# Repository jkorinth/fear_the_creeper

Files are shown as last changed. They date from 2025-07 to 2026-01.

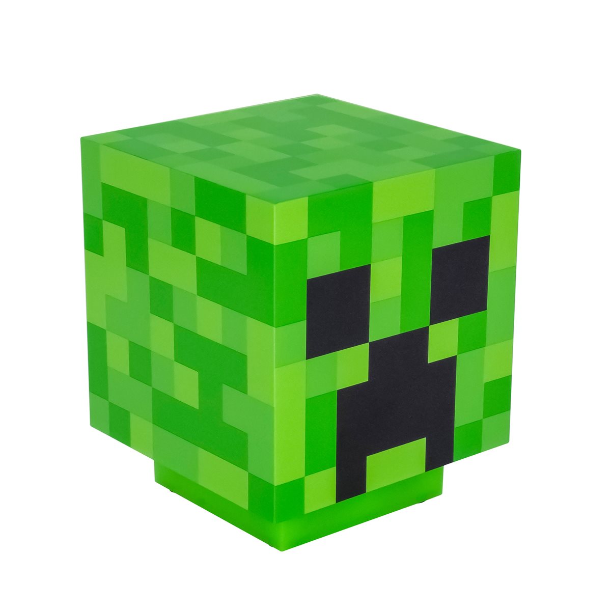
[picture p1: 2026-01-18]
creeper_head.jpg

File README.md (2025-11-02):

# Creeper Gadget

![Creeper][creeper.png]

A toy gadget that produces light + sound effects like a Creeper in Minecraft.
Fun little project which covers software, electronics, mechanical design elements.
And Mincraft. :)

## Hardware

* 35mm x 35mm 2-layer PCB w/dedicated ground plane
* Microcontroller: ATtiny85
* CR23xx battery
* Accelerometer: IIS328DQTR (low power, interrupt)
* piezzo buzzer
* 2x discrete LEDs (LP T67F)
* battery holder
* On/Off switch

## Mechanical

* 3D printed 40mm x 40mm x 10mm case
* cutout at Creeper "face" reveals black PCB underneath
* snap-fit lid for battery replacement
* hanger bracket for keyrings or lanyards

## Software

* IRQ-triggered sequence on motion detection
* fuse ignition sounds
* accelerating blinking
* explosion sound

## Tools

* Electronic Design: KiCAD
* Mechanical Design: FreeCAD
* Software Design: Arduino

## Current State ✅❌

### Summary
* i2c via I2CTinyBB: ✅
* irqs from IIS328DQ: ✅
* ISP: ✅
* LEDs: ✅
* KiBot CI/CD: kinda
* buzzer: ❌
* wake from sleep: ❌
* tilt switch: ❌

### Issues / Next Steps
Idea with the analog switch (74HC4066BQ) was nice, but it creates several new
problems: In closed state it has a small resistance (70R-180R), which creates
an accidental voltage divider with a pull-up on the line. Signal integrity was
good enough for i2c, strange enough, but both INT and BUZ suffered severe
issues when traversing the switch. The wake-up from deep sleep works fine when
bridging the `I2C` and `I2C_MCU` nets, but then ISP no longer works (which was
the whole point of having the analog switch in the first place).

The tilt switch has the issue that it generates only very short pulses, which
don't reliably wake up the MCU. Simplest solution would be a small capacitor
which slows down the rising edge, but I haven't tried that yet. Or a flip-flop
but that seems like total overkill.

This ISP issue is bugging me and I want to solve it. My next attempt would be
to use MOSFETs: 1x P-channel for the +3V pullups on SCL and SDA, 3x N-channel
for the SCL, SDA and INT signals. Costs more board space, but if I can use sth
like SOT-323, it may not be significant (also, the 74HC4066BQ footprint would
be gone, freeing up some little space).

Other issues:
  1. The power switch doesn't break the circuit from the debug connector.
  2. Add testpoints to make debugging less painful.

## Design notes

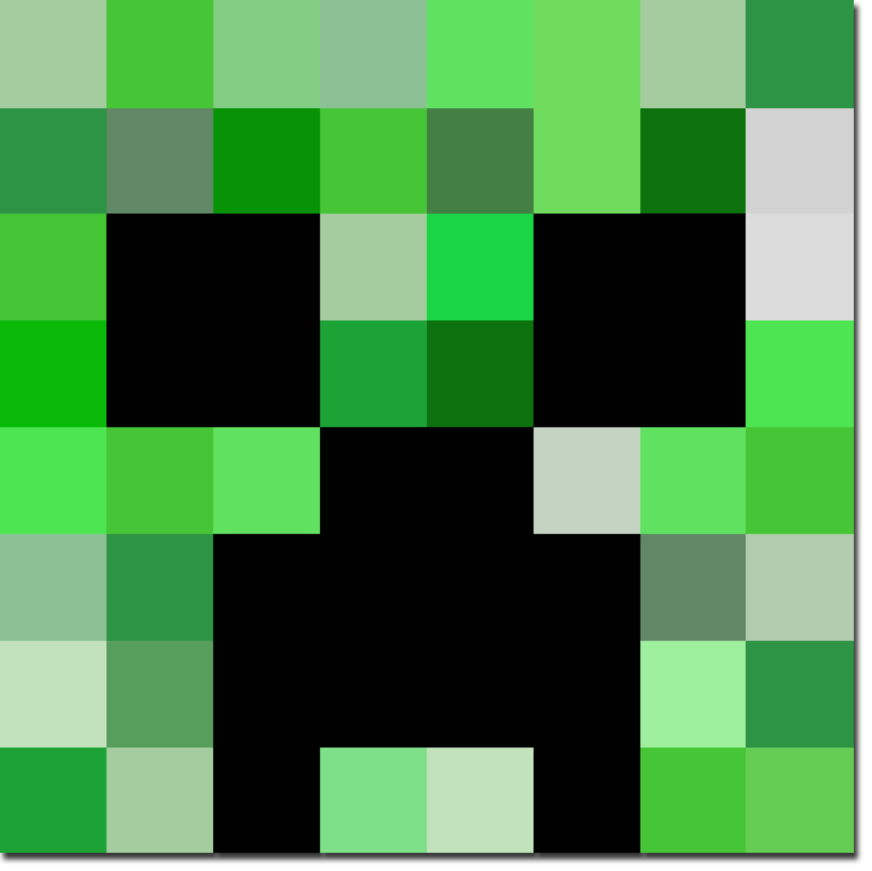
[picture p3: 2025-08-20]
case/creeper_face.webp

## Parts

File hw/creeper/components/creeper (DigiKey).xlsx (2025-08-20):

Reference | Qty | Value | Footprint | # | Manufacturer | MPN | SolderJoints | Original Part | Original Manufacturer | Matched Part Number | Matched Manufacturer | Part Match | Description | Qty | Selected Offers | Selected Distributor | Selected Distributor SKU | Selected Offers (Distributor Link) | Stock | Unit Price | Total Quantity | Total Price
BT1 | 1 | 3005 | creeper:BAT_3005 | 1 | Keystone Electronics | 3005 | 2 | 3005 | Keystone Electronics | 3005 | Keystone Electronics | Exact | Battery Holder: THM, 1 Coin Cell, 23mm, PhosBronze/Tin-Nickel | Keystone Electronics 3005 | 5 | DigiKey 36-3005-ND (https://octopart.com/opatz8j6/a1) | DigiKey | 36-3005-ND (https://octopart.com/opatz8j6/a1) | https://octopart.com/opatz8j6/a1 | 1407 | 0.43 | 5 | 2.15
C_ACC1, C_MCU1 | 2 | 100nF | Capacitor_SMD:C_0603_1608Metric_Pad1.08x0.95mm_HandSolder | 3 | KEMET | C0603C101K3RACTU | 2 | C0603C101K3RACTU | KEMET | C0603C101K3RACTU | KEMET | Exact | Ceramic Capacitor, Multilayer, Ceramic, 25V, 10% +Tol, 10% -Tol, X7R, 15% TC, 0.0001uF, Surface Mount, 0603 | 10 | DigiKey 399-14936-1-ND (https://octopart.com/opatz8j6/a1) | DigiKey | 399-14936-1-ND (https://octopart.com/opatz8j6/a1) | https://octopart.com/opatz8j6/a1 | 10727 | 0.109 | 10 | 1.09
C_PWR1 | 1 | 10uF | Capacitor_SMD:C_0805_2012Metric_Pad1.18x1.45mm_HandSolder | 4 | Murata Electronics | GRM21BZ71E106KE15L | 2 | GRM21BZ71E106KE15L | Murata Electronics | GRM21BZ71E106KE15L | Murata Electronics | Exact | 25V 10uF X7R ±10% 0805 Multilayer Ceramic Capacitors MLCC - SMD/SMT ROHS | 5 | DigiKey 490-GRM21BZ71E106KE15LCT-ND (https://octopart.com/opatz8j6/a1) | DigiKey | 490-GRM21BZ71E106KE15LCT-ND (https://octopart.com/opatz8j6/a1) | https://octopart.com/opatz8j6/a1 | 42211 | 0.25 | 5 | 1.25
D1, D2 | 2 | LED | creeper:LED_LG_T671-L2N1-1-Z | 5 | ams-OSRAM USA INC. | LG T67F-R1T1-24-1-20-R18-Z | 2 | LG T67F-R1T1-24-1-20-R18-Z | ams-OSRAM USA INC. | LG T67F-R1T1-24-1-20-R18-Z | ams-OSRAM USA INC. | Exact | SMT LED With Integrated Reflector | 10 | DigiKey 475-LGT67F-R1T1-24CT-ND (https://octopart.com/opatz8j6/a1) | DigiKey | 475-LGT67F-R1T1-24CT-ND (https://octopart.com/opatz8j6/a1) | https://octopart.com/opatz8j6/a1 | 24231 | 0.162 | 10 | 1.62
R1 | 1 | 0R | Resistor_SMD:R_0603_1608Metric_Pad0.98x0.95mm_HandSolder | 6 | Vishay Dale | CRCW06030000Z0EA | 2 | CRCW06030000Z0EA | Vishay Dale | CRCW06030000Z0EA | Vishay Dale | Exact | STANDARD THICK FILM CHIP RESISTOR Metal Glaze/thick Film, 0.1W, 0ohm, Surface Mount, 0603 | 5 | DigiKey 541-0.0GCT-ND (https://octopart.com/opatz8j6/a1) | DigiKey | 541-0.0GCT-ND (https://octopart.com/opatz8j6/a1) | https://octopart.com/opatz8j6/a1 | 1061434 | 0.014 | 10 | 0.14
U1 | 1 | ATtiny85V-10SU | Package_SO:SOIC-8_5.3x5.3mm_P1.27mm | 10 | Microchip Technology | ATTINY85V-10SU | 8 | ATTINY85V-10SU | Microchip Technology | ATTINY85V-10SU | Microchip Technology | Exact | AVR, 8K Flash, 512B Ee And SRAM, Usi, Adc, 8 Pins - 1.8V, 10MHZ, SOIC, Ind Temp, | 5 | DigiKey ATTINY85V-10SU-ND (https://octopart.com/opatz8j6/a1) | DigiKey | ATTINY85V-10SU-ND (https://octopart.com/opatz8j6/a1) | https://octopart.com/opatz8j6/a1 | 6425 | 1.27 | 5 | 6.35
U2 | 1 | LIS2DH12TR | creeper:LGA-12_STM | 11 | STMicroelectronics | LIS2DH12TR | 12 | LIS2DH12TR | STMicroelectronics | LIS2DH12TR | STMicroelectronics | Exact | Stmicroelectronics - LIS2DH12TR - 3-AXIS Accelerometer, Digital, LGA-12 | 5 | DigiKey 497-14851-1-ND (https://octopart.com/opatz8j6/a1) | DigiKey | 497-14851-1-ND (https://octopart.com/opatz8j6/a1) | https://octopart.com/opatz8j6/a1 | 30341 | 1.03 | 5 | 5.16

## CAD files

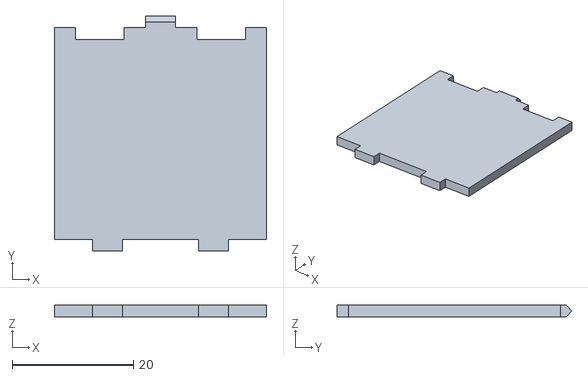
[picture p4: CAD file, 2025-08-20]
case/v3/creeper_case_v3_lidOD.stl
35.0 x 38.8 x 2.00

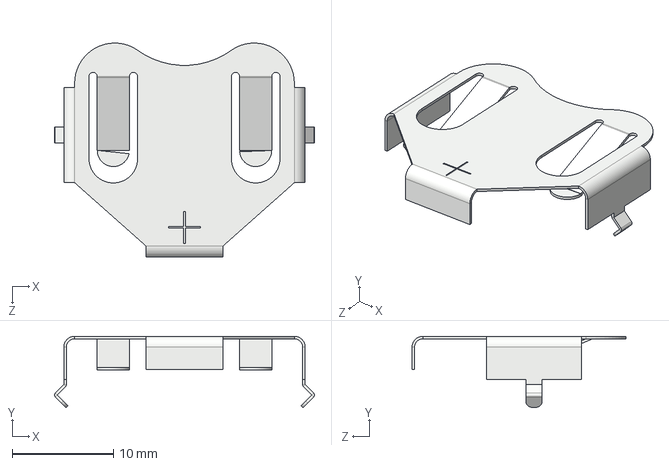
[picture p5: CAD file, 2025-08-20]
hw/creeper/components/3005/3005.step
25.7 x 7.06 x 21.1 mm

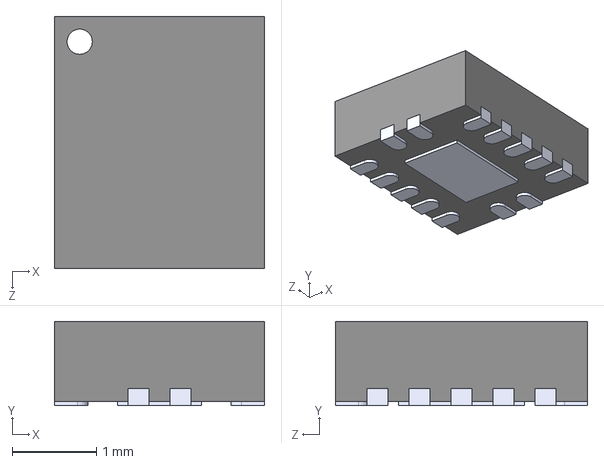
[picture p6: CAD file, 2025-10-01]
hw/creeper/components/74HC4066BQ-Q100/74HC4066BQ-Q100_11.step
2.50 x 1.00 x 3.00 mm

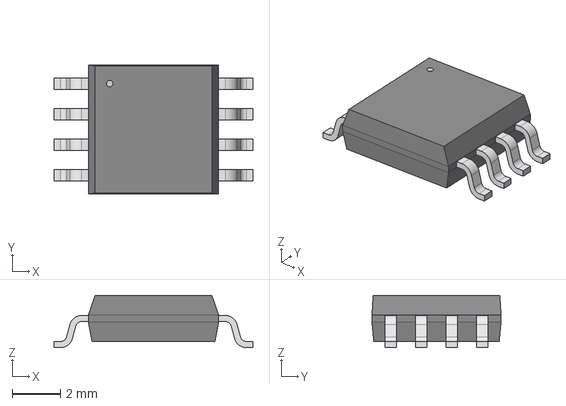
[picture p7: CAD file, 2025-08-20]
hw/creeper/components/ATTINY85V0-10SU/8S2_ATM.step
8.26 x 5.36 x 2.16 mm

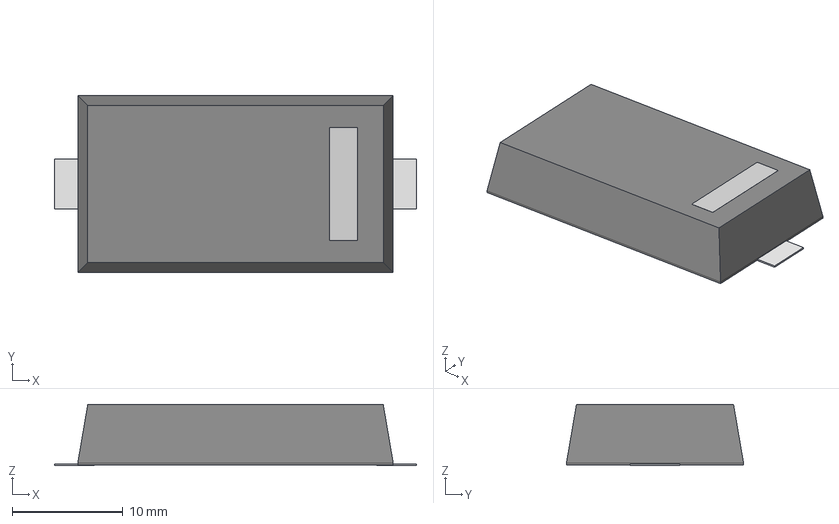
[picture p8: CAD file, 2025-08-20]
hw/creeper/components/BH-74G-5-P/BH-74G-5-P_ADM.step
32.7 x 16.0 x 5.52 mm

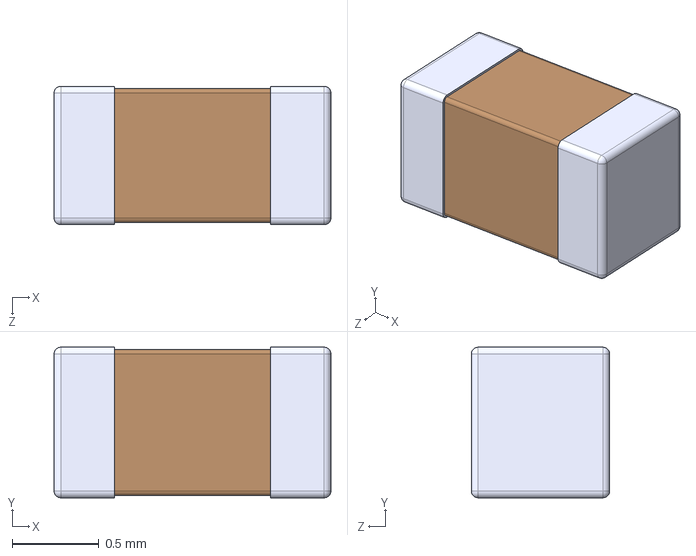
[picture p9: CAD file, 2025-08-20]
hw/creeper/components/C0603C101K3RACTU/C0603C101K3RACTU.STEP
1.60 x 0.87 x 0.8 mm

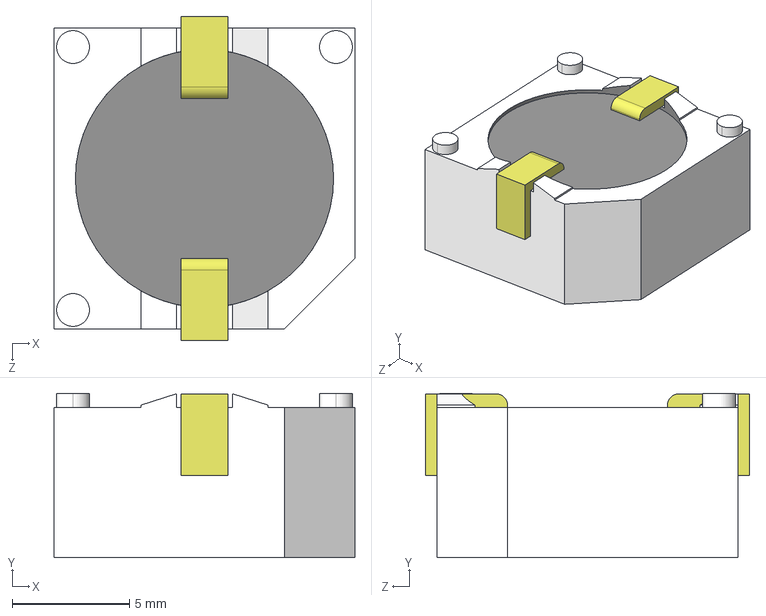
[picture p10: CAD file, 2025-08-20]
hw/creeper/components/CMT-1270S-SMT-TR/CMT-1270S-SMT.step
12.8 x 7.00 x 13.8 mm

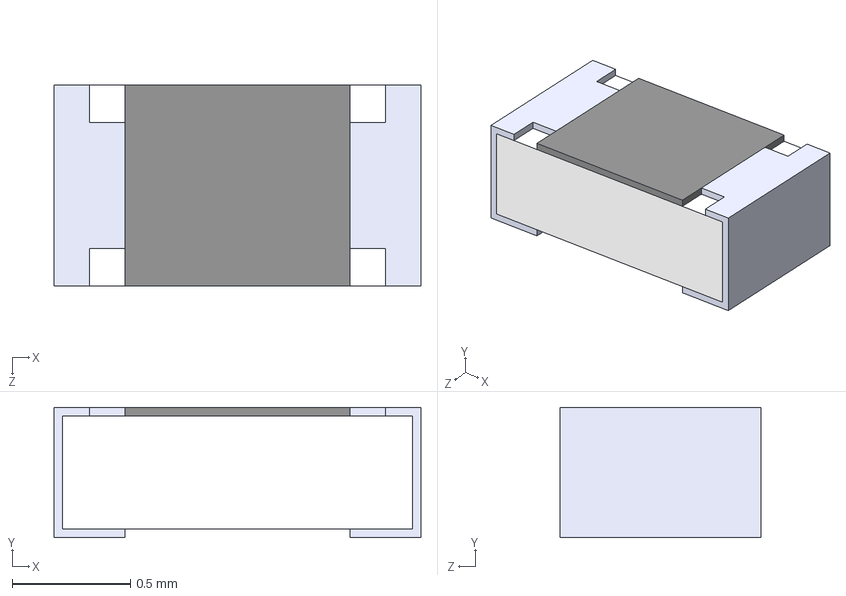
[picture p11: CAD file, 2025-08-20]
hw/creeper/components/CRCW060310K0JNEA/CRCW060310K0JNEA.STEP
1.55 x 0.55 x 0.85 mm

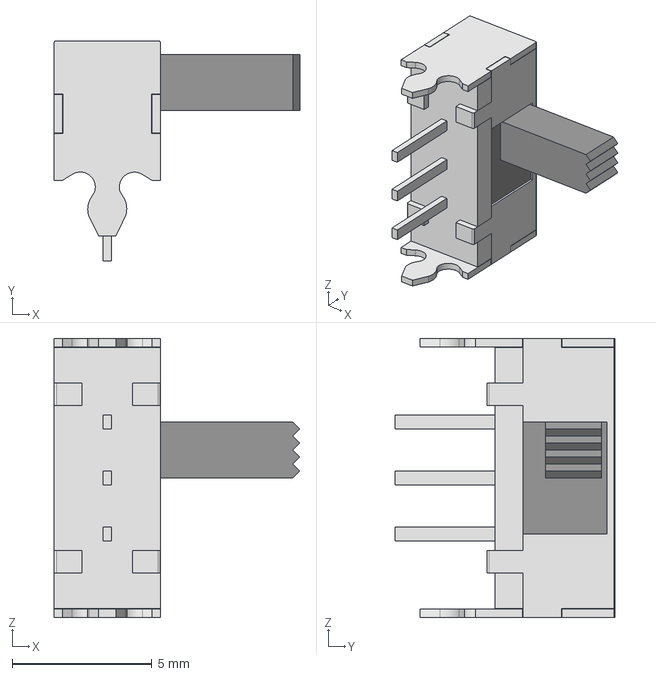
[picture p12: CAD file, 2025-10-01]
hw/creeper/components/EG1213/EG1213.step
8.80 x 7.90 x 10.00 mm

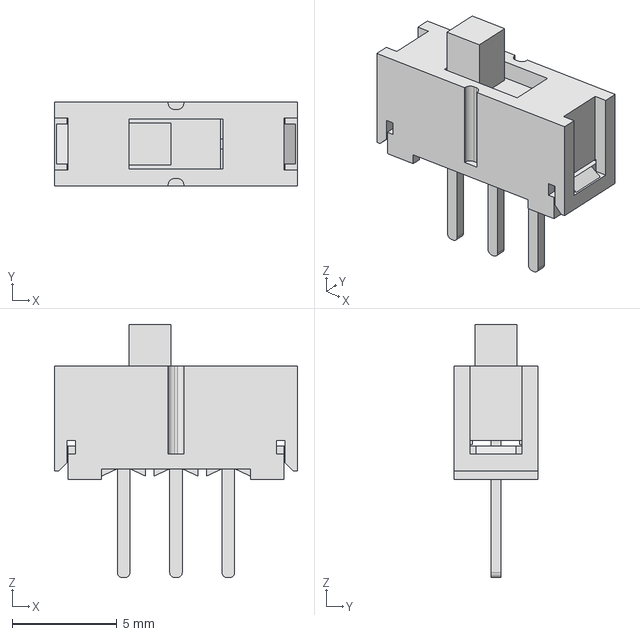
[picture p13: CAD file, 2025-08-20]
hw/creeper/components/EG1218/EG1218.step
11.6 x 4.00 x 12.1 mm

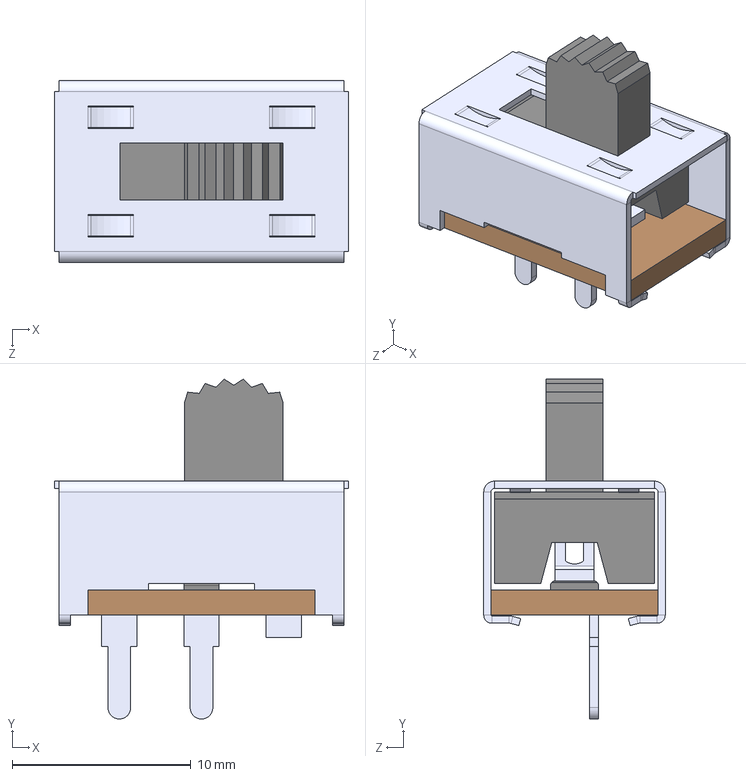
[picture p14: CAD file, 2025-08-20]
hw/creeper/components/GF-123-0054/GF-123-0054--3DModel-STEP-56544.STEP
16.5 x 19.0 x 10.2 mm

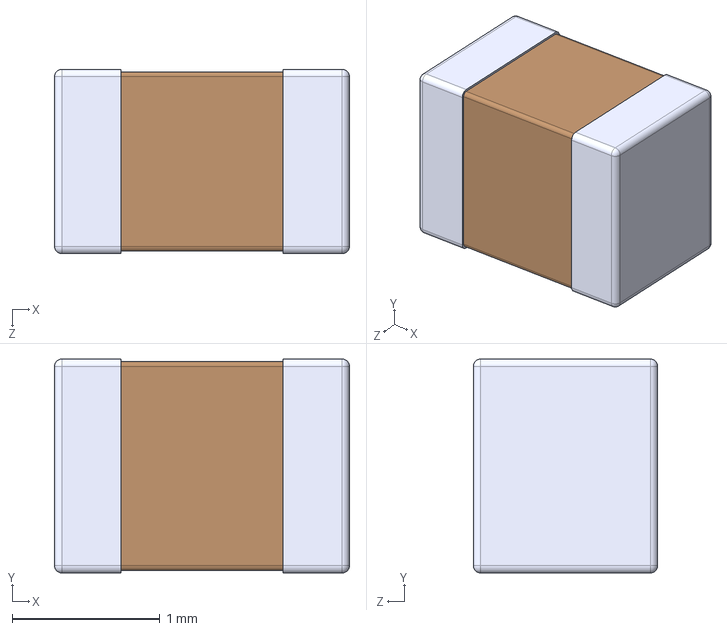
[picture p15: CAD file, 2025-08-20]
hw/creeper/components/GRM21BZ71E106KE15L/GRM21BZ71E106KE15L.STEP
2.00 x 1.45 x 1.25 mm

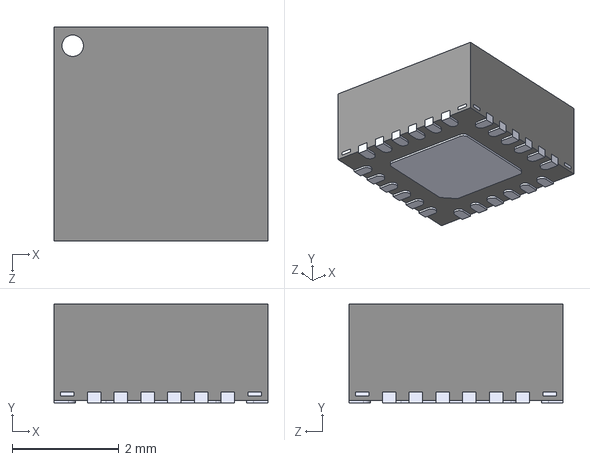
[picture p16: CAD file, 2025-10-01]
hw/creeper/components/IIS328DQTR.zip/IIS328DQTR.step
4.00 x 1.85 x 4.00 mm

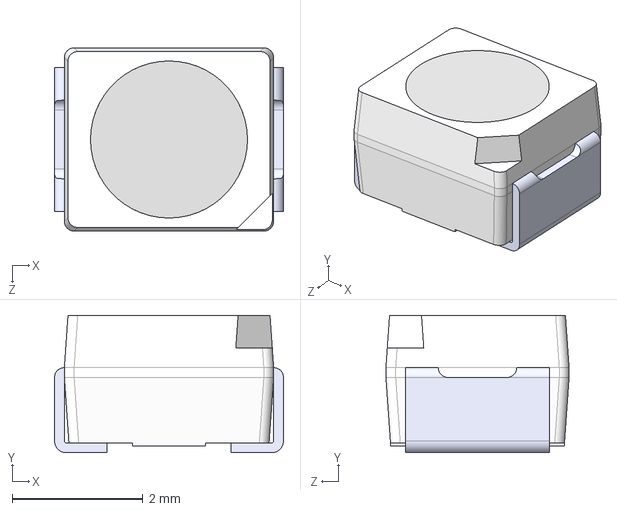
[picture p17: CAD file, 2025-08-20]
hw/creeper/components/LG_T67F-R1T1-24/LG T67F-R1T1-24.step
3.50 x 2.10 x 2.80 mm

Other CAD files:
hw/creeper/components/LIS2DH12TR/LGA-12_STM.step
hw/creeper/components/LP_T67F/LED_LPT67F-P1R2-35-1-20-R18_AMS.step
hw/creeper/components/PT_1241PFQ/PT-1241PFQ_MAL.step
case/v2/creeper_case_v2_case.stl
case/v2/creeper_case_v2_face.stl
case/v3/creeper_case_v3_case.stl
case/v3/creeper_case_v3_face.stl
hw/creeper/components/BH-74G-5-P/BH-74G-5-P_ADM.stl
hw/creeper/components/LP_T67F/LED_LPT67F-P1R2-35-1-20-R18_AMS.stl
hw/creeper/components/SMT-0825-S-2-R/SMT-0825-S-2-R.step
hw/creeper/components/SMT_1324_TW_1V_HT_R/SMT-1324-TW-1V-HT-R.step

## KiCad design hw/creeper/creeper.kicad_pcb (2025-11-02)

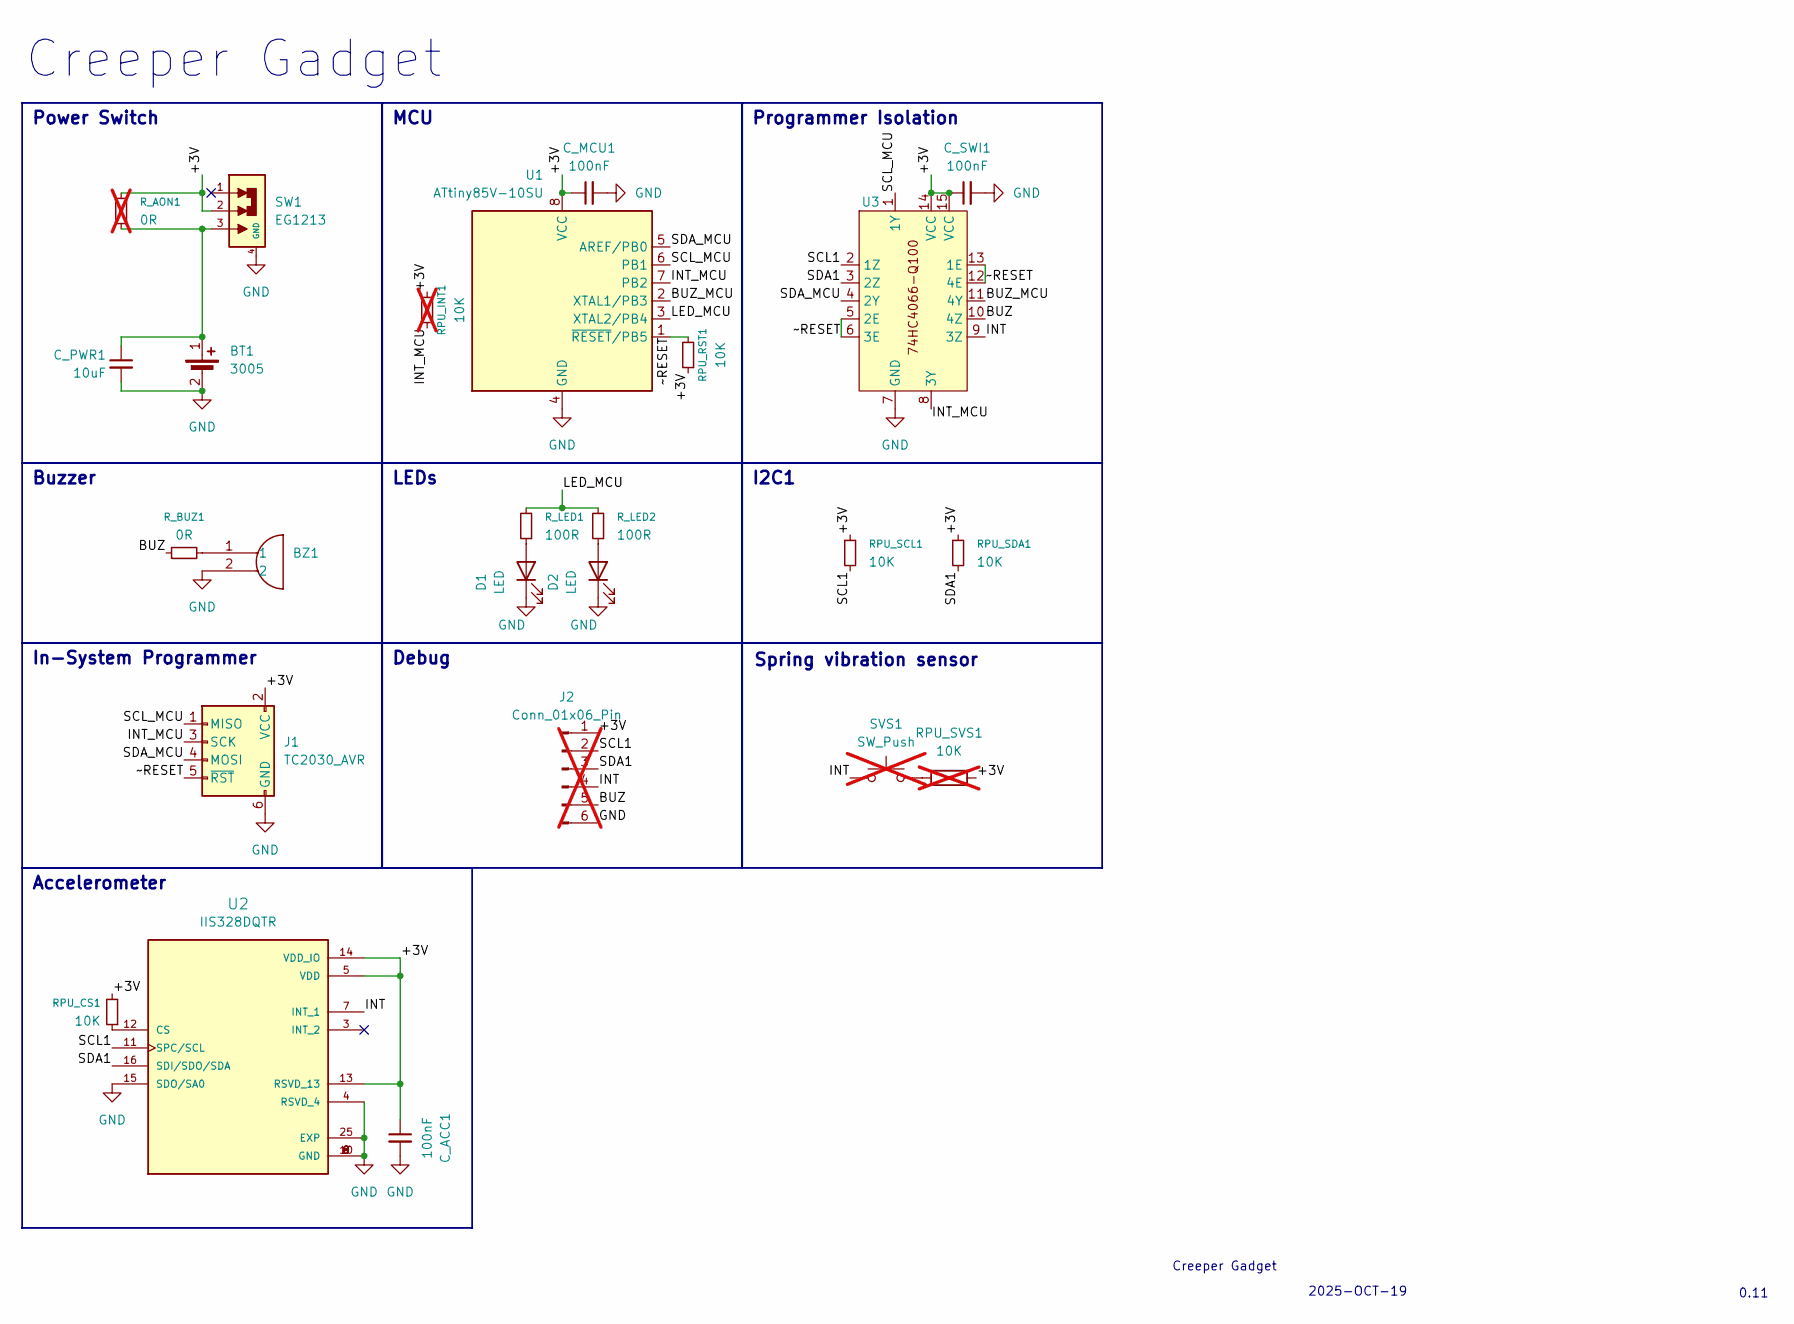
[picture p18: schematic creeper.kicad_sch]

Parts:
BT1: 3005; BAT_3005; MPN 3005
BZ1: XDCR_SMT-0825-S-2-R
C_ACC1: 100nF; C_0603_1608Metric_Pad1.08x0.95mm_HandSolder; MPN C0603C101K3RACTU
C_MCU1: 100nF; C_0603_1608Metric_Pad1.08x0.95mm_HandSolder; MPN C0603C101K3RACTU
C_PWR1: 10uF; C_0805_2012Metric_Pad1.18x1.45mm_HandSolder; MPN GRM21BZ71E106KE15L
C_SWI1: 100nF; C_0603_1608Metric_Pad1.08x0.95mm_HandSolder; MPN C0603C101K3RACTU
D1, D2: LED; LED_LG_T671-L2N1-1-Z; MPN LG T67F-R1T1-24-1-20-R18-Z
J1: TC2030_AVR; CON_TC2030_outlined
J2: Conn_01x06_Pin; PinHeader_1x06_P2.54mm_Vertical; not fitted
RPU_CS1: 10K; R_0603_1608Metric_Pad0.98x0.95mm_HandSolder; MPN CRCW060310K0JNEA
RPU_INT1: 10K; R_0603_1608Metric_Pad0.98x0.95mm_HandSolder; MPN CRCW060310K0JNEA; not fitted
RPU_RST1: 10K; R_0603_1608Metric_Pad0.98x0.95mm_HandSolder; MPN CRCW060310K0JNEA
RPU_SCL1: 10K; R_0603_1608Metric_Pad0.98x0.95mm_HandSolder; MPN CRCW060310K0JNEA
RPU_SDA1: 10K; R_0603_1608Metric_Pad0.98x0.95mm_HandSolder; MPN CRCW060310K0JNEA
RPU_SVS1: 10K; R_0603_1608Metric_Pad0.98x0.95mm_HandSolder; not fitted
R_AON1: 0R; R_0603_1608Metric_Pad0.98x0.95mm_HandSolder; not fitted
R_BUZ1: 0R; R_0603_1608Metric_Pad0.98x0.95mm_HandSolder; MPN CRCW06030000Z0EA
R_LED1, R_LED2: 100R; R_0603_1608Metric_Pad0.98x0.95mm_HandSolder; MPN CRCW060343R0JNEA
SVS1: SW_Push; SW_180xxP_Spring_Vibration_Sensor; not fitted
SW1: EG1213; SW_EG1213; MPN EG1213
U1: ATtiny85V-10SU; SOIC-8_5.3x5.3mm_P1.27mm; MPN ATTINY85V-10SU
U2: IIS328DQTR; IIS328DQTR_QFN50P400X400X185-25N; PARTREV 3; DigiKey_Part_Number 497-15701-1-ND
U3: QFN50P300X250X100-15N; MPN 74HC4066BQ-Q100,11

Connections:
/+3V: C_ACC1.1, C_MCU1.1, C_SWI1.1, J1.2 (VCC), J2.1, RPU_CS1.2, RPU_INT1.2, RPU_RST1.1, RPU_SCL1.1, RPU_SDA1.1, RPU_SVS1.2, R_AON1.1, SW1.2, U1.8 (VCC), U2.5 (VDD), U2.13 (RSVD_13), U2.14 (VDD_IO), U3.14 (VCC), U3.15 (VCC)
/BUZ: J2.5, R_BUZ1.1, U3.10 (4Z)
/BUZ_MCU: U1.2 (XTAL1/PB3), U3.11 (4Y)
/INT: J2.4, SVS1.1, U2.7 (INT_1), U3.9 (3Z)
/INT_MCU: J1.3 (SCK), RPU_INT1.1, U1.7 (PB2), U3.8 (3Y)
/LED_MCU: R_LED1.2, R_LED2.2, U1.3 (XTAL2/PB4)
/SCL1: J2.2, RPU_SCL1.2, U2.11 (SPC/SCL), U3.2 (1Z)
/SCL_MCU: J1.1 (MISO), U1.6 (PB1), U3.1 (1Y)
/SDA1: J2.3, RPU_SDA1.2, U2.16 (SDI/SDO/SDA), U3.3 (2Z)
/SDA_MCU: J1.4 (MOSI), U1.5 (AREF/PB0), U3.4 (2Y)
/~RESET: J1.5 (~RST), RPU_RST1.2, U1.1 (~RESET/PB5), U3.5 (2E), U3.6 (3E), U3.12 (4E), U3.13 (1E)
GND: BT1.2 (-), BZ1.2, C_ACC1.2, C_MCU1.2, C_PWR1.2, C_SWI1.2, D1.1 (K), D2.1 (K), J1.6 (GND), J2.6, SW1.4 (GND), U1.4 (GND), U2.4 (RSVD_4), U2.6 (GND), U2.8 (GND), U2.9 (GND), U2.10 (GND), U2.15 (SDO/SA0), U2.25 (EXP), U3.7 (GND)
unnamed: BT1.1 (+), C_PWR1.1, R_AON1.2, SW1.3
unnamed: BZ1.1, R_BUZ1.2
unnamed: D1.2 (A), R_LED1.1
unnamed: D2.2 (A), R_LED2.1
unnamed: RPU_SVS1.1, SVS1.2
unnamed: RPU_CS1.1, U2.12 (CS)

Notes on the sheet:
LEDs
Creeper Gadget
MCU
Creeper Gadget
I2C1
2025-OCT-19
Buzzer
Debug
Power Switch
Programmer Isolation
In-System Programmer
0.11
Spring vibration sensor
Accelerometer

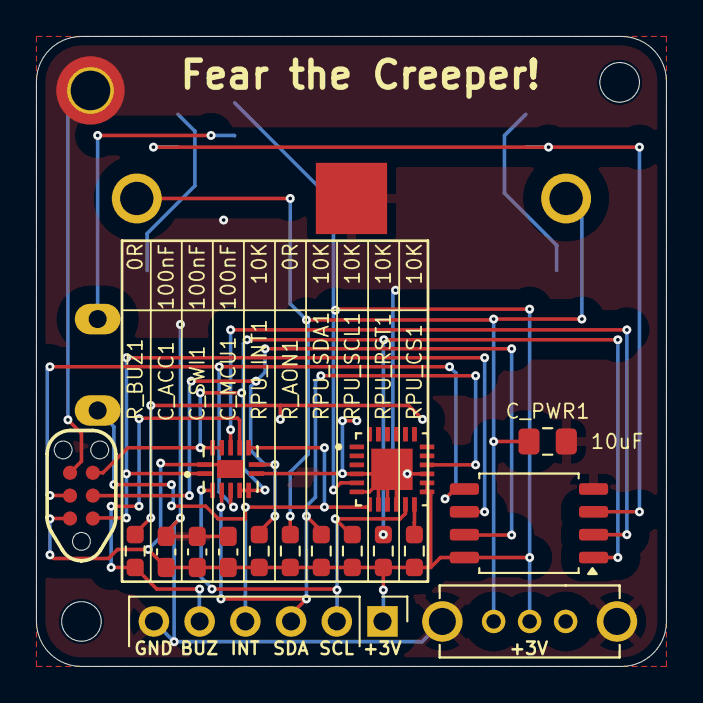
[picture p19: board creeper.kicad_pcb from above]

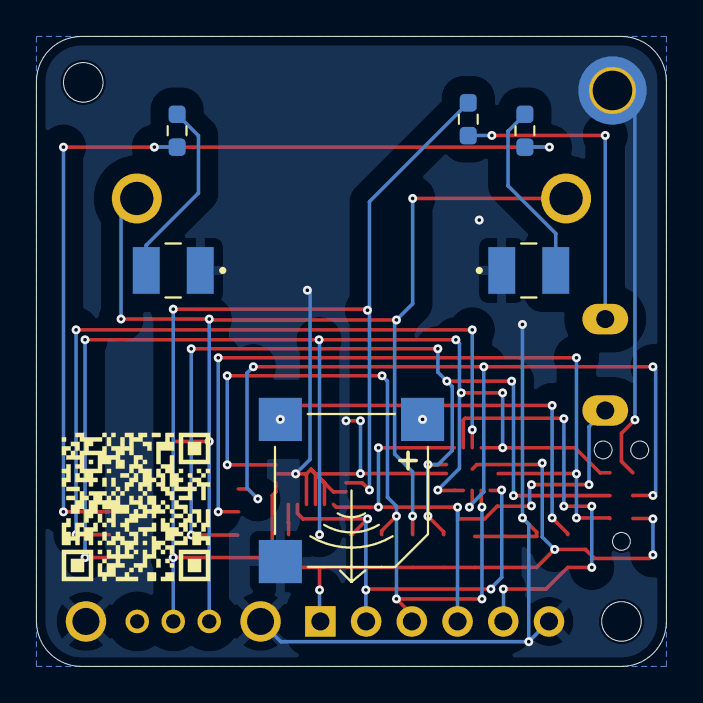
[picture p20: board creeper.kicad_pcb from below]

Board: 2 copper layers, 35.0 x 35.0 mm, 26 parts (8 on the bottom side), 18 nets.

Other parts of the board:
QR1: https://github.com/jkorinth/fear_the_creeper; github_jkorinth-fear_the_creeper

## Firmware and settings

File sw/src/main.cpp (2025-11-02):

#include <Arduino.h>
#include <I2CTinyBB.h>
#include <avr/interrupt.h>
#include <avr/power.h>
#include <avr/sleep.h>
#include "iis328dq.h"

#define INT 2
#define BUZ 3
#define LED 4

#define IIS328DQ_ADDR 0x18
#define REG_WHO_AM_I 0x0f
#define REG_CTRL_REG1 0x20

#define ARR_SZ(x) (sizeof((x)) / sizeof(*(x)))

volatile int _play = 1;

void iis328dq_init()
{
	uint8_t d = 0;
	for (size_t i = 0; i < IIS328DQ_INIT_COUNT; ++i) {
		uint8_t tmp[2] = { iis328dq_shake_init[i].reg, iis328dq_shake_init[i].value };
		I2CWrite(IIS328DQ_ADDR, tmp, 2);
		I2CReadReg(IIS328DQ_ADDR, tmp[0], &d, 1);
	}
}

void setup() {
  uint8_t d;
  clock_prescale_set(clock_div_1);
  DDRB = (1 << PB4) | (1 << PB3) | (1 << PB1) | (1 << PB0);
  PORTB = 0;
  MCUCR = 0; // low level-triggered interrupt
  GIMSK |= (1 << INT0);  // Enable INT0 external interrupt
  I2CInit(0, 1, 10);
  sei();
  iis328dq_init();
}

// Interrupt Service Routine for INT0
ISR(INT0_vect) {}

void enterSleep() {
  uint8_t d = 0;
  MCUCR = 0;
  GIMSK |= (1 << INT0);  // Enable INT0 external interrupt
  
  set_sleep_mode(SLEEP_MODE_PWR_DOWN);  // Set deep sleep mode
  sleep_enable();  // Enable sleep bit
  sei();  // Enable global interrupts
  sleep_cpu();  // Go to sleep - execution stops here
  
  // Code resumes here after wake-up
  sleep_disable();  // Disable sleep bit
  GIMSK &= ~(1 << INT0);  // disable INT0 external interrupt
  I2CReadReg(IIS328DQ_ADDR, IIS328DQ_INT1_SRC, &d, 1);
  _play = 1;
}

void play()
{
	int countdown = 700;
	while (countdown > 0) {
		digitalWrite(LED, HIGH);
		delay(25);
		digitalWrite(LED, LOW);
		countdown *= 0.84;
		delay(countdown);
	}
	_play = 0;
}

void loop() {
	if (_play) {
		play();
	}
	enterSleep();
}

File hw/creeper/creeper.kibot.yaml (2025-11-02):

kibot:
  version: 1

import:
- file: ExportProject
- file: JLCPCB
  definitions:
    _KIBOT_MANF_DIR: Manufacturers/JLCPCB
    _KIBOT_POS_PRE_TRANSFORM: '[''_kicost_rename'', ''_rot_footprint'']'
    _KIBOT_BOM_ENABLED: 'false'
- file: PCB2Blender_2_1
- file: PCBWay
  definitions:
    _KIBOT_MANF_DIR: Manufacturers/PCBWay

preflight:
  drc:
    dont_stop: true
    format: HTML,RPT
  erc:
    dont_stop: true
    format: HTML,RPT

outputs:
- name: basic_export_3d_step
  comment: 3D model in STEP format
  type: export_3d
  dir: 3D
  options:
    format: step
- name: basic_export_3d_stl
  comment: 3D model in STL format
  type: export_3d
  dir: 3D
  options:
    format: stl
- name: gerber_modern
  comment: Gerbers in modern format, recommended by the standard
  type: gerber
  dir: Gerbers
  layers:
  - layer: F.Cu
    suffix: F_Cu
    description: Front copper
  - layer: F.Mask
    suffix: F_Mask
    description: Front soldermask (negative)
  - layer: B.Cu
    suffix: B_Cu
    description: Bottom copper
  - layer: B.Mask
    suffix: B_Mask
    description: Bottom soldermask (negative)
  - layer: F.Silkscreen
    suffix: F_Silkscreen
    description: Front silkscreen (artwork)
  - layer: B.Silkscreen
    suffix: B_Silkscreen
    description: Bottom silkscreen (artwork)
  - layer: Edge.Cuts
    suffix: Edge_Cuts
    description: Board shape
  - layer: B.Courtyard
    suffix: B_Courtyard
    description: Bottom courtyard area
  - layer: F.Courtyard
    suffix: F_Courtyard
    description: Front courtyard area
- name: basic_ibom
  comment: Interactive HTML BoM
  type: ibom
  dir: Assembly
- name: classic_netlist
  comment: Schematic netlist in KiCad format
  type: netlist
  dir: Export
- name: ipc_netlist
  comment: IPC-D-356 netlist for testing
  type: netlist
  dir: Export
  options:
    format: ipc
- name: basic_pdf_sch_print
  comment: Schematic in PDF format
  type: pdf_sch_print
  dir: Schematic
- name: basic_render_3d_top
  comment: 3D view from top
  type: render_3d
  dir: 3D
  options:
    ray_tracing: true
    orthographic: true
- name: basic_render_3d_30deg
  comment: 3D view from 30 degrees
  type: render_3d
  dir: 3D
  output_id: 30deg
  options:
    ray_tracing: true
    rotate_x: 3
    rotate_z: -2
- name: basic_render_3d_bottom
  comment: 3D view from bottom
  type: render_3d
  dir: 3D
  options:
    ray_tracing: true
    orthographic: true
    view: bottom
- name: navigate_results
  comment: "Generates a web page to navigate the results"
  type: navigate_results
  dir: navigate
  options:
    title: "Fear the Creeper!"


...
definitions:
  _KIBOT_MANF_DIR_COMP: Manufacturers
  _KIBOT_GERBER_LAYERS: "- layer: 'F.Cu'\n        suffix: 'F_Cu'\n        description:\
    \ 'Front copper'\n      - layer: 'F.Mask'\n        suffix: 'F_Mask'\n        description:\
    \ 'Front soldermask (negative)'\n      - layer: 'B.Cu'\n        suffix: 'B_Cu'\n\
    \        description: 'Bottom copper'\n      - layer: 'B.Mask'\n        suffix:\
    \ 'B_Mask'\n        description: 'Bottom soldermask (negative)'\n      - layer:\
    \ 'F.Silkscreen'\n        suffix: 'F_Silkscreen'\n        description: 'Front\
    \ silkscreen (artwork)'\n      - layer: 'B.Silkscreen'\n        suffix: 'B_Silkscreen'\n\
    \        description: 'Bottom silkscreen (artwork)'\n      - layer: 'Edge.Cuts'\n\
    \        suffix: 'Edge_Cuts'\n        description: 'Board shape'"

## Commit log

2025-08-20 feat(pcb): first manufactured PCB version
    [3005.step, 8S2_ATM.step, BH-74G-5-P_ADM.step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]
2025-08-20 bump: version 0.5.9 → 0.6.0
2025-08-20 add first drafts for 3D printed cases
    [creeper_case_v2_case.stl, creeper_case_v2_face.stl, creeper_case_v2_lid.stl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]
2025-08-20 feat(pcb): v0.7
    * added TC2030_AVR pogo debug plug connector
    * added isolating resistors to stabilize ISP
    * fixed missing connections of battery holder
    * added 0R bridge for always-on w/o switch
    * moved mounting hole out of case opening
    * did manual place and route
    [creeper.kicad_pcb, creeper.kicad_sch]
2025-08-20 bump: version 0.6.0 → 0.7.0
2025-10-01 feat: rev. 0.10: use analog switch for programmer isolation
    [74HC4066BQ-Q100_11.step, EG1213.step, IIS328DQTR.step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]
2025-10-02 feat(pcb): update constraints, fix via sizes
    [creeper.kicad_pcb]
2025-10-19 feat: v0.11: replace accelerometer with optional spring vibration sensor
    [creeper.kicad_pcb, creeper.kicad_sch]
2025-11-01 fix(pcb): remove solder mask margin from pins
    BREAKING CHANGE:
2025-11-01 fix(sch+pcb): update footprints, reset DNP
    [creeper.kicad_pcb, creeper.kicad_sch]
2025-11-02 fix(sw): WIP: software for IIS328DQ build
    * weird glitches, INT and INT_MCU seem to differ
    * maybe a capacitance issue, the INT_MCU dropping much slower than INT
2025-11-02 fix(pcb): sync'ed footprints back, excluded mounting hole footprints
    [creeper.kicad_pcb]
2025-11-02 ci(kibot): add KiBot configuration and fix some minor issues
    [creeper.kicad_pcb, creeper.kicad_sch]
2025-11-02 fix(sw): add missing submodule for I2CTinyBB
